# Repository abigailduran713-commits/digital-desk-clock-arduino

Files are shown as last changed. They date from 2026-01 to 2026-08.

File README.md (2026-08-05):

# Arduino Digital Desk Clock

## Project Overview
This project is a standalone digital desk clock built using an Arduino Uno, a DS3231 real-time clock module, and a 16x2 LCD.

The clock features a three-button menu system, user-adjustable time settings, interval-based reminders, and a visual LED alert. A DS3231 RTC provides accurate timekeeping, while non-blocking timing allows the system to remain responsive while handling user input, display updates, and reminders.

After testing the circuit on a breadboard, the complete system was converted into a custom PCB designed in KiCad. The PCB has been designed and is currently awaiting fabrication and assembly.

## Features
- 16x2 LCD display
- Time and date display
- Accurate timekeeping using a DS3231 RTC module
- User-adjustable time through the LCD menu
- Menu navigation using three push buttons: UP, DOWN, and MODE
- Interval-based reminders
- Enable and disable reminder settings
- Blinking LED alert during active reminders
- Custom PCB designed in KiCad

## Hardware Used 

### Breadboard Prototype
- Arduino Uno R3
- 16x2 LCD display
- DS3231 Real-time clock module
- Push buttons (x3)
- LED + resistor
- Potentiometer (LCD contrast)
- Breadboard and jumper wires

### PCB Version
- Custom PCB designed in KiCad
- Arduino Uno R3 and headers
- RTC module and headers
- LCD module and headers
- Push-button inputs
- LED + resistors
- Potentiometer

## How It Works
The DS3231 real-time clock module maintains the current time independently of the Arduino. The Arduino reads the time from the RTC through I2C communication and displays it on the 16x2 LCD.

The user interacts with the clock through three push buttons. A menu-driven state machine allows the buttons to perform different actions depending on the active screen, including navigating settings, changing the displayed time, selecting reminder intervals, and enabling or disabling reminders.

Reminder timing is handled without long blocking delays. The program uses `millis()` to manage LCD updates, button input, reminder checks, and the blinking LED alert while keeping the system responsive.

The circuit was initially developed and tested on a breadboard. After confirming the main hardware and software functions, the schematic and PCB layout were created in KiCad for a more permanent version of the project.

## PCB Design
After completing the breadboard prototype, the circuit was recreated as a schematic in KiCad and converted into a custom PCB layout.

The design process included:
- Assignming schematic symbols and footprints
- Running electrical rules checks
- Definin the board outline
- Placing components
- Routing signal and power traces
- Adding a ground plane
- Running design rules checks
- Generating Gerber and drill files for fabrication

## Future Improvements
- Fabricate and assemble the custom PCB
- Test and validate the assembled board
- Design a compact enclosure
- Revise the PCB if issues are found during physical testing

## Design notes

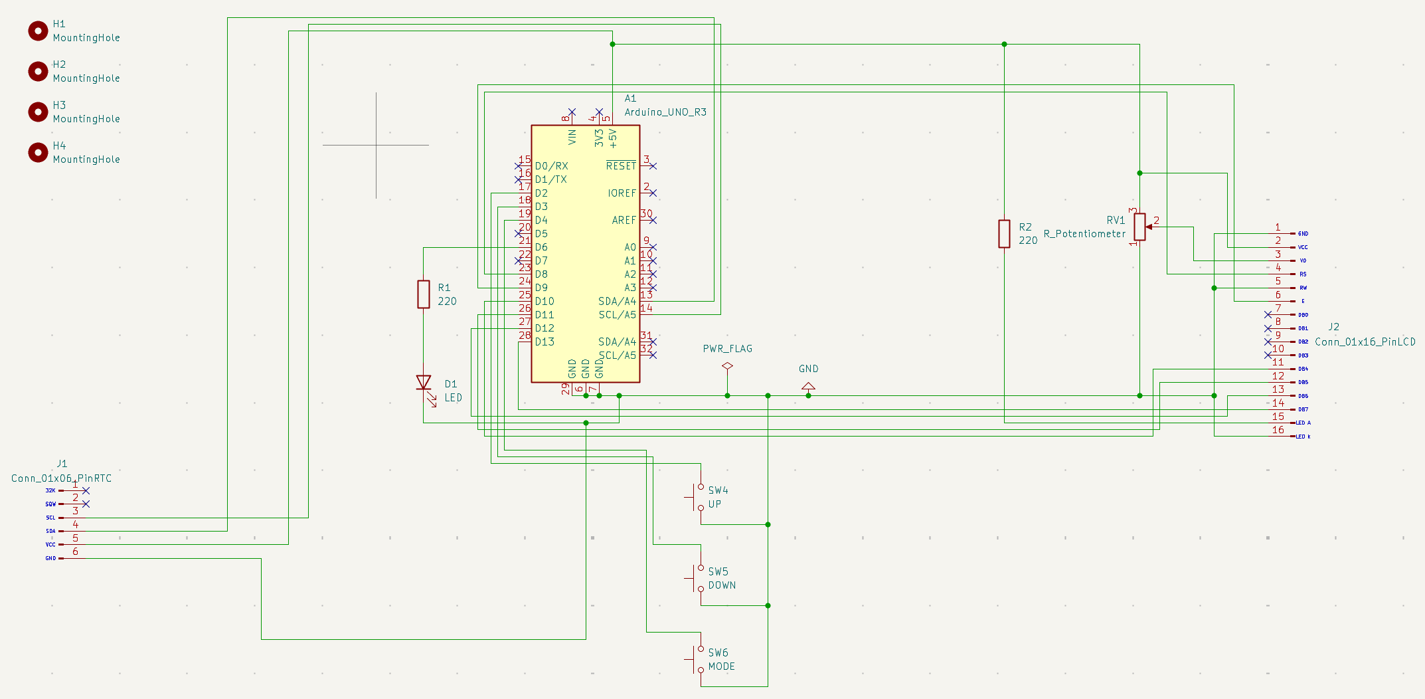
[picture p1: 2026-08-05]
Images/KiCad-schematic.png

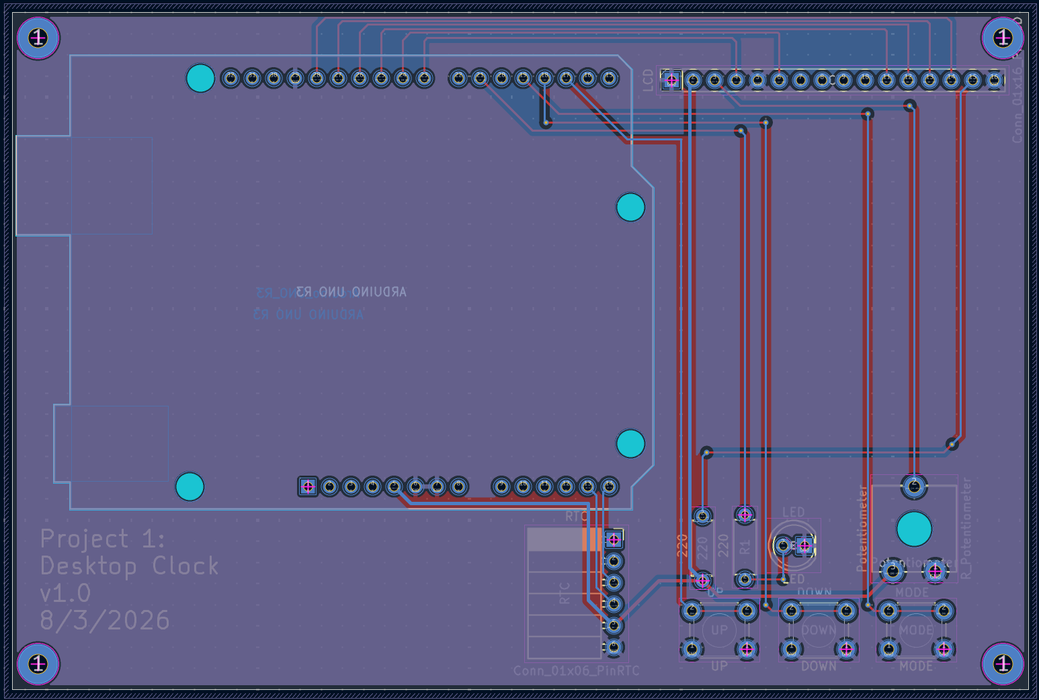
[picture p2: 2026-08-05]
Images/PCB-layout.png

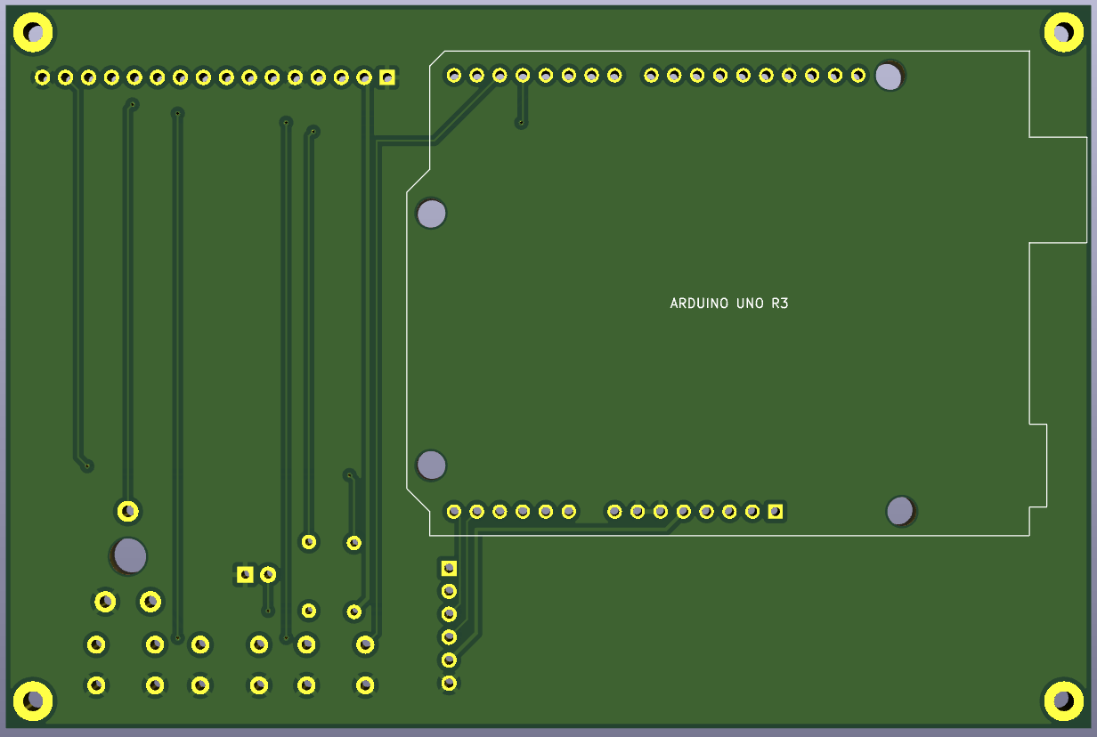
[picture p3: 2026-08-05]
Images/PCB-3D-view-back.png

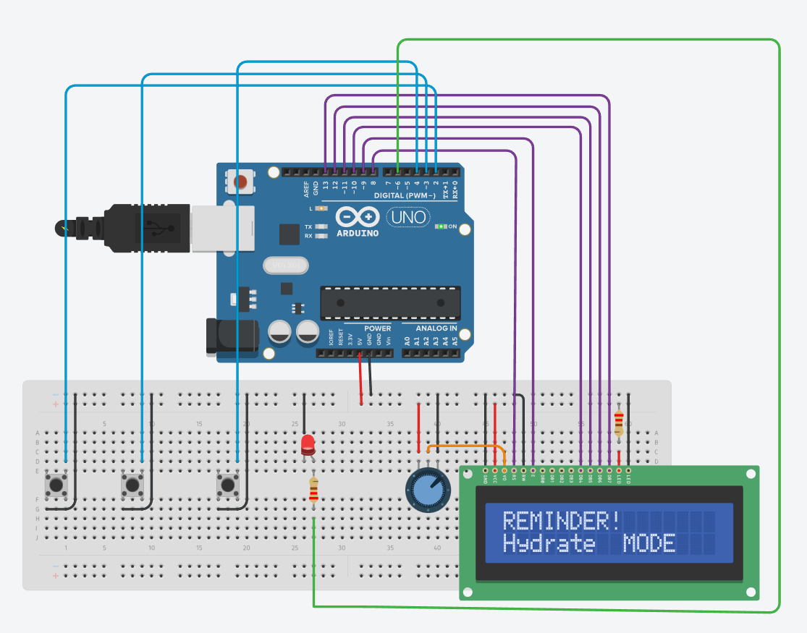
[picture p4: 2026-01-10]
Images/Tinkercad-simulation.png

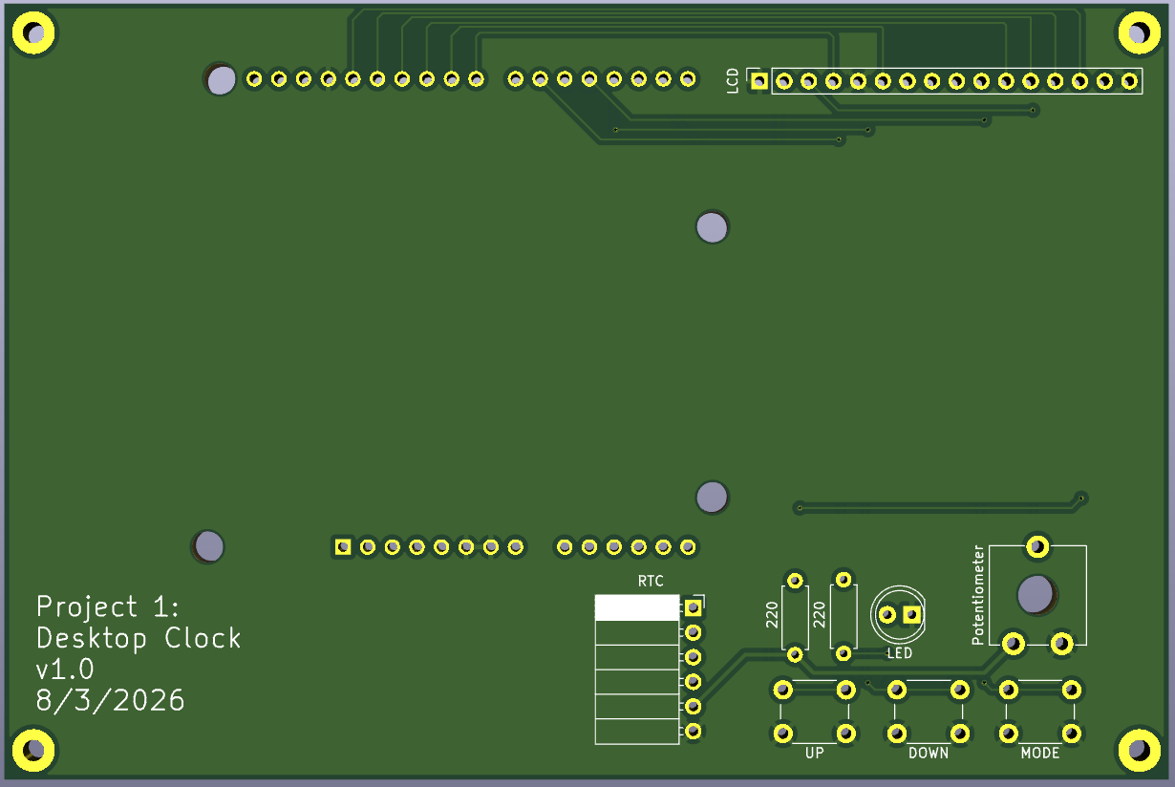
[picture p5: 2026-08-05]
Images/PCB-3D-view-front.png

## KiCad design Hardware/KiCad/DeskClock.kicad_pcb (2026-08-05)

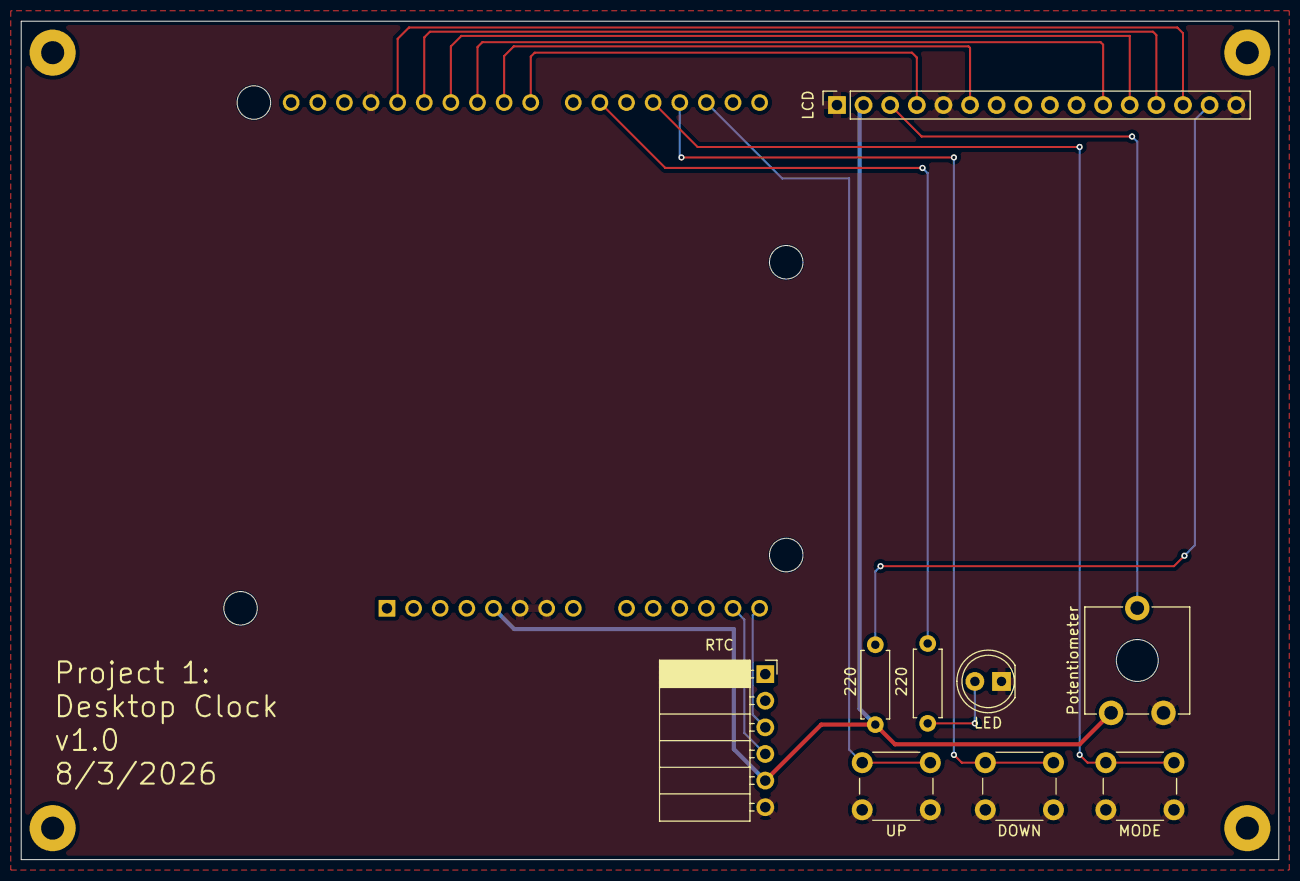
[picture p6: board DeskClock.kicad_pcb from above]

Board: 2 copper layers, 120.0 x 80.0 mm, 14 parts (1 on the bottom side), 17 nets.

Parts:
220: 220; R_Axial_DIN0207_L6.3mm_D2.5mm_P7.62mm_Horizontal
ARDUINO UNO R3: Arduino_UNO_R3; Arduino_UNO_R3_WithMountingHoles
DOWN: DOWN; SW_PUSH_6mm_H8.5mm
H1, H2, H3, H4: MountingHole; MountingHole_2.2mm_M2_Pad
LCD: Conn_01x16_PinLCD; PinSocket_1x16_P2.54mm_Vertical
LED: LED; LED_D5.0mm
MODE: MODE; SW_PUSH_6mm_H8.5mm
Potentiometer: R_Potentiometer; Potentiometer_ACP_CA9-V10_Vertical_Hole
R1: 220; R_Axial_DIN0207_L6.3mm_D2.5mm_P7.62mm_Horizontal
RTC: Conn_01x06_PinRTC; PinSocket_1x06_P2.54mm_Horizontal
UP: UP; SW_PUSH_6mm_H8.5mm

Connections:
GND: ARDUINO UNO R3.6 (GND), ARDUINO UNO R3.7 (GND), ARDUINO UNO R3.29 (GND), DOWN.1, LCD.1, LCD.5, LCD.16, LED.1 (K), MODE.1, Potentiometer.1, RTC.6, UP.1
unnamed: 220.1, ARDUINO UNO R3.5 (+5V), LCD.2, Potentiometer.3, RTC.5
unnamed: ARDUINO UNO R3.17 (D2), UP.2
unnamed: ARDUINO UNO R3.18 (D3), DOWN.2
unnamed: ARDUINO UNO R3.19 (D4), MODE.2
unnamed: ARDUINO UNO R3.21 (D6), R1.1
unnamed: ARDUINO UNO R3.23 (D8), LCD.4
unnamed: ARDUINO UNO R3.24 (D9), LCD.6
unnamed: ARDUINO UNO R3.25 (D10), LCD.11
unnamed: ARDUINO UNO R3.26 (D11), LCD.12
unnamed: ARDUINO UNO R3.27 (D12), LCD.13
unnamed: ARDUINO UNO R3.28 (D13), LCD.14
unnamed: LED.2 (A), R1.2
unnamed: ARDUINO UNO R3.14 (SCL/A5), RTC.3
unnamed: ARDUINO UNO R3.13 (SDA/A4), RTC.4
unnamed: LCD.3, Potentiometer.2
unnamed: 220.2, LCD.15

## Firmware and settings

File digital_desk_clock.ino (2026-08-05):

#include <Wire.h>
#include <RTClib.h>
#include <LiquidCrystal.h>

// ======================================================
// PIN ASSIGNMENTS
// ======================================================

// LCD: RS, E, D4, D5, D6, D7
LiquidCrystal lcd(8, 9, 10, 11, 12, 13);

// Buttons connect between these pins and GND.
const byte BTN_UP   = 2;
const byte BTN_DOWN = 3;
const byte BTN_MODE = 4;

// LED: D6 -> 220-ohm resistor -> LED anode
// LED cathode -> GND
const byte LED_REMINDER = 6;

// ======================================================
// RTC
// ======================================================

RTC_DS3231 rtc;

// ======================================================
// USER INTERFACE
// ======================================================

enum Screen {
  SCREEN_CLOCK,
  SCREEN_STATUS,
  SCREEN_INTERVAL,
  SCREEN_REMINDER_TOGGLE,
  SCREEN_SET_HOUR,
  SCREEN_SET_MINUTE,
  SCREEN_REMINDER
};

Screen screen = SCREEN_CLOCK;

// ======================================================
// REMINDER SETTINGS
// ======================================================

bool remindersEnabled = true;
byte reminderIntervalMinutes = 30;

bool reminderActive = false;
unsigned long reminderStartedAt = 0;
const unsigned long REMINDER_DURATION_MS = 6000;

int lastTriggeredMinute = -1;
int lastTriggeredHour = -1;

// ======================================================
// LED BLINK SETTINGS
// ======================================================

bool ledState = false;
unsigned long lastLedChange = 0;
const unsigned long LED_BLINK_INTERVAL_MS = 500;

// ======================================================
// BUTTON HANDLING
// ======================================================

struct Button {
  byte pin;
  bool stableState;
  bool previousReading;
  unsigned long changedAt;
  unsigned long pressedAt;
  bool longPressHandled;
};

Button upButton = {
  BTN_UP, HIGH, HIGH, 0, 0, false
};

Button downButton = {
  BTN_DOWN, HIGH, HIGH, 0, 0, false
};

Button modeButton = {
  BTN_MODE, HIGH, HIGH, 0, 0, false
};

const unsigned long DEBOUNCE_MS = 35;
const unsigned long LONG_PRESS_MS = 1500;

// ======================================================
// TIME-SETTING VALUES
// ======================================================

byte editHour24 = 0;
byte editMinute = 0;

// ======================================================
// DISPLAY HELPERS
// ======================================================

const char *dayNames[] = {
  "Sun", "Mon", "Tue", "Wed", "Thu", "Fri", "Sat"
};

void clearLine(byte row) {
  lcd.setCursor(0, row);
  lcd.print("                ");
}

void printTwoDigits(byte value) {
  if (value < 10) {
    lcd.print('0');
  }

  lcd.print(value);
}

byte convertTo12Hour(byte hour24) {
  byte hour12 = hour24 % 12;

  if (hour12 == 0) {
    hour12 = 12;
  }

  return hour12;
}

bool isPM(byte hour24) {
  return hour24 >= 12;
}

// ======================================================
// BUTTON FUNCTIONS
// ======================================================

void updateButton(Button &button) {
  bool reading = digitalRead(button.pin);

  if (reading != button.previousReading) {
    button.changedAt = millis();
    button.previousReading = reading;
  }

  if (millis() - button.changedAt >= DEBOUNCE_MS) {
    if (reading != button.stableState) {
      button.stableState = reading;

      if (button.stableState == LOW) {
        button.pressedAt = millis();
        button.longPressHandled = false;
      }
    }
  }
}

bool buttonWasReleased(Button &button) {
  static bool upPreviouslyPressed = false;
  static bool downPreviouslyPressed = false;
  static bool modePreviouslyPressed = false;

  bool *previouslyPressed = nullptr;

  if (button.pin == BTN_UP) {
    previouslyPressed = &upPreviouslyPressed;
  } else if (button.pin == BTN_DOWN) {
    previouslyPressed = &downPreviouslyPressed;
  } else {
    previouslyPressed = &modePreviouslyPressed;
  }

  if (button.stableState == LOW) {
    *previouslyPressed = true;
  }

  if (*previouslyPressed && button.stableState == HIGH) {
    *previouslyPressed = false;

    if (!button.longPressHandled) {
      return true;
    }
  }

  return false;
}

bool buttonLongPressed(Button &button) {
  if (
    button.stableState == LOW &&
    !button.longPressHandled &&
    millis() - button.pressedAt >= LONG_PRESS_MS
  ) {
    button.longPressHandled = true;
    return true;
  }

  return false;
}

// ======================================================
// TIME SETTING
// ======================================================

void beginTimeSetting() {
  DateTime now = rtc.now();

  editHour24 = now.hour();
  editMinute = now.minute();

  screen = SCREEN_SET_HOUR;
  lcd.clear();
}

void saveTimeToRTC() {
  DateTime now = rtc.now();

  // Preserve the current date and change only the time.
  // Seconds reset to zero.
  rtc.adjust(
    DateTime(
      now.year(),
      now.month(),
      now.day(),
      editHour24,
      editMinute,
      0
    )
  );

  lastTriggeredMinute = -1;
  lastTriggeredHour = -1;

  screen = SCREEN_CLOCK;
  lcd.clear();

  lcd.setCursor(0, 0);
  lcd.print("Time saved!");

  delay(800);
  lcd.clear();
}

// ======================================================
// REMINDER FUNCTIONS
// ======================================================

void beginReminder() {
  reminderActive = true;
  reminderStartedAt = millis();
  screen = SCREEN_REMINDER;

  ledState = true;
  digitalWrite(LED_REMINDER, HIGH);

  lcd.clear();
}

void endReminder() {
  reminderActive = false;
  ledState = false;
  digitalWrite(LED_REMINDER, LOW);

  screen = SCREEN_CLOCK;
  lcd.clear();
}

void updateReminderLED() {
  if (!reminderActive) {
    ledState = false;
    digitalWrite(LED_REMINDER, LOW);
    return;
  }

  if (millis() - lastLedChange >= LED_BLINK_INTERVAL_MS) {
    lastLedChange = millis();
    ledState = !ledState;
    digitalWrite(LED_REMINDER, ledState);
  }
}

void checkReminder(const DateTime &now) {
  if (!remindersEnabled || reminderActive) {
    return;
  }

  bool correctMinute =
    now.minute() % reminderIntervalMinutes == 0;

  // Use a small time window rather than requiring the loop to
  // execute at exactly second zero.
  bool triggerWindow = now.second() < 3;

  bool notAlreadyTriggered =
    now.minute() != lastTriggeredMinute ||
    now.hour() != lastTriggeredHour;

  if (correctMinute && triggerWindow && notAlreadyTriggered) {
    lastTriggeredMinute = now.minute();
    lastTriggeredHour = now.hour();
    beginReminder();
  }
}

// ======================================================
// SCREEN DRAWING
// ======================================================

void drawClockScreen(const DateTime &now) {
  byte hour12 = convertTo12Hour(now.hour());

  clearLine(0);
  lcd.setCursor(0, 0);

  lcd.print(hour12);
  lcd.print(':');
  printTwoDigits(now.minute());
  lcd.print(isPM(now.hour()) ? " PM" : " AM");

  clearLine(1);
  lcd.setCursor(0, 1);

  lcd.print(dayNames[now.dayOfTheWeek()]);
  lcd.print(' ');
  printTwoDigits(now.month());
  lcd.print('/');
  printTwoDigits(now.day());
  lcd.print('/');
  lcd.print(now.year() % 100);
}

void drawStatusScreen() {
  clearLine(0);
  lcd.setCursor(0, 0);
  lcd.print("Reminders: ");
  lcd.print(remindersEnabled ? "ON" : "OFF");

  clearLine(1);
  lcd.setCursor(0, 1);
  lcd.print("Every ");
  lcd.print(reminderIntervalMinutes);
  lcd.print(" min");
}

void drawIntervalScreen() {
  clearLine(0);
  lcd.setCursor(0, 0);
  lcd.print("SET INTERVAL");

  clearLine(1);
  lcd.setCursor(0, 1);
  lcd.print(reminderIntervalMinutes);
  lcd.print(" min  UP/DOWN");
}

void drawReminderToggleScreen() {
  clearLine(0);
  lcd.setCursor(0, 0);
  lcd.print("REMINDERS");

  clearLine(1);
  lcd.setCursor(0, 1);
  lcd.print(remindersEnabled ? "ON" : "OFF");
  lcd.print("  UP/DOWN");
}

void drawSetHourScreen() {
  clearLine(0);
  lcd.setCursor(0, 0);
  lcd.print("SET HOUR");

  clearLine(1);
  lcd.setCursor(0, 1);

  lcd.print(convertTo12Hour(editHour24));
  lcd.print(':');
  printTwoDigits(editMinute);
  lcd.print(isPM(editHour24) ? " PM" : " AM");
}

void drawSetMinuteScreen() {
  clearLine(0);
  lcd.setCursor(0, 0);
  lcd.print("SET MINUTE");

  clearLine(1);
  lcd.setCursor(0, 1);

  lcd.print(convertTo12Hour(editHour24));
  lcd.print(':');
  printTwoDigits(editMinute);
  lcd.print(isPM(editHour24) ? " PM" : " AM");
}

void drawReminderScreen() {
  clearLine(0);
  lcd.setCursor(0, 0);
  lcd.print("REMINDER!");

  clearLine(1);
  lcd.setCursor(0, 1);
  lcd.print("MODE=OK");
}

// ======================================================
// BUTTON ACTIONS
// ======================================================

void handleUpPress() {
  switch (screen) {
    case SCREEN_INTERVAL:
      reminderIntervalMinutes += 5;

      if (reminderIntervalMinutes > 120) {
        reminderIntervalMinutes = 5;
      }
      break;

    case SCREEN_REMINDER_TOGGLE:
      remindersEnabled = !remindersEnabled;
      break;

    case SCREEN_SET_HOUR:
      editHour24 = (editHour24 + 1) % 24;
      break;

    case SCREEN_SET_MINUTE:
      editMinute = (editMinute + 1) % 60;
      break;

    case SCREEN_REMINDER:
      // Extend the current reminder.
      reminderStartedAt = millis();
      break;

    default:
      break;
  }
}

void handleDownPress() {
  switch (screen) {
    case SCREEN_INTERVAL:
      if (reminderIntervalMinutes <= 5) {
        reminderIntervalMinutes = 120;
      } else {
        reminderIntervalMinutes -= 5;
      }
      break;

    case SCREEN_REMINDER_TOGGLE:
      remindersEnabled = !remindersEnabled;
      break;

    case SCREEN_SET_HOUR:
      editHour24 =
        editHour24 == 0 ? 23 : editHour24 - 1;
      break;

    case SCREEN_SET_MINUTE:
      editMinute =
        editMinute == 0 ? 59 : editMinute - 1;
      break;

    case SCREEN_REMINDER:
      endReminder();
      break;

    default:
      break;
  }
}

void handleModeShortPress() {
  switch (screen) {
    case SCREEN_CLOCK:
      screen = SCREEN_STATUS;
      break;

    case SCREEN_STATUS:
      screen = SCREEN_INTERVAL;
      break;

    case SCREEN_INTERVAL:
      screen = SCREEN_REMINDER_TOGGLE;
      break;

    case SCREEN_REMINDER_TOGGLE:
      screen = SCREEN_CLOCK;
      break;

    case SCREEN_SET_HOUR:
      screen = SCREEN_SET_MINUTE;
      break;

    case SCREEN_SET_MINUTE:
      saveTimeToRTC();
      return;

    case SCREEN_REMINDER:
      endReminder();
      return;
  }

  lcd.clear();
}

// ======================================================
// SETUP
// ======================================================

void setup() {
  pinMode(BTN_UP, INPUT_PULLUP);
  pinMode(BTN_DOWN, INPUT_PULLUP);
  pinMode(BTN_MODE, INPUT_PULLUP);

  pinMode(LED_REMINDER, OUTPUT);
  digitalWrite(LED_REMINDER, LOW);

  Wire.begin();
  lcd.begin(16, 2);

  if (!rtc.begin()) {
    lcd.clear();
    lcd.print("RTC NOT FOUND");

    while (true) {
      delay(10);
    }
  }

  lcd.clear();
  lcd.print("Desk Clock");
  lcd.setCursor(0, 1);
  lcd.print("Starting...");

  delay(800);
  lcd.clear();
}

// ======================================================
// MAIN LOOP
// ======================================================

void loop() {
  updateButton(upButton);
  updateButton(downButton);
  updateButton(modeButton);

  DateTime now = rtc.now();

  checkReminder(now);
  updateReminderLED();

  if (
    reminderActive &&
    millis() - reminderStartedAt >= REMINDER_DURATION_MS
  ) {
    endReminder();
  }

  // Holding MODE enters the clock-setting menu.
  if (
    screen != SCREEN_REMINDER &&
    buttonLongPressed(modeButton)
  ) {
    beginTimeSetting();
  }

  if (buttonWasReleased(upButton)) {
    handleUpPress();
    lcd.clear();
  }

  if (buttonWasReleased(downButton)) {
    handleDownPress();
    lcd.clear();
  }

  if (buttonWasReleased(modeButton)) {
    handleModeShortPress();
  }

  switch (screen) {
    case SCREEN_CLOCK:
      drawClockScreen(now);
      break;

    case SCREEN_STATUS:
      drawStatusScreen();
      break;

    case SCREEN_INTERVAL:
      drawIntervalScreen();
      break;

    case SCREEN_REMINDER_TOGGLE:
      drawReminderToggleScreen();
      break;

    case SCREEN_SET_HOUR:
      drawSetHourScreen();
      break;

    case SCREEN_SET_MINUTE:
      drawSetMinuteScreen();
      break;

    case SCREEN_REMINDER:
      drawReminderScreen();
      break;
  }

  delay(10);
}
